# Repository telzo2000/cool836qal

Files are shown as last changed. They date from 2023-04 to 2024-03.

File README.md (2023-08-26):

# cool836qal

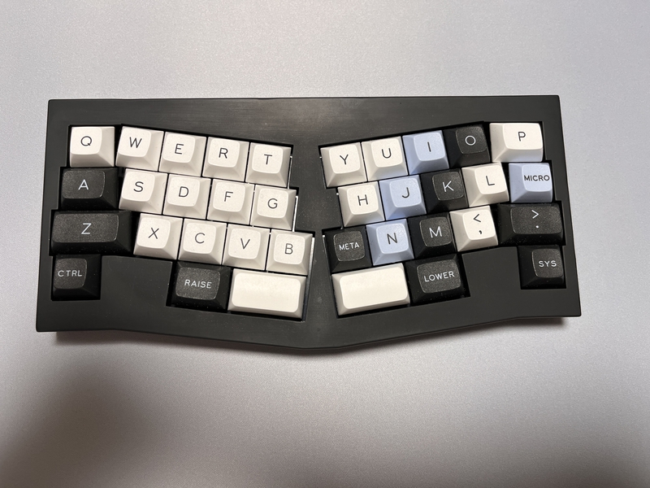
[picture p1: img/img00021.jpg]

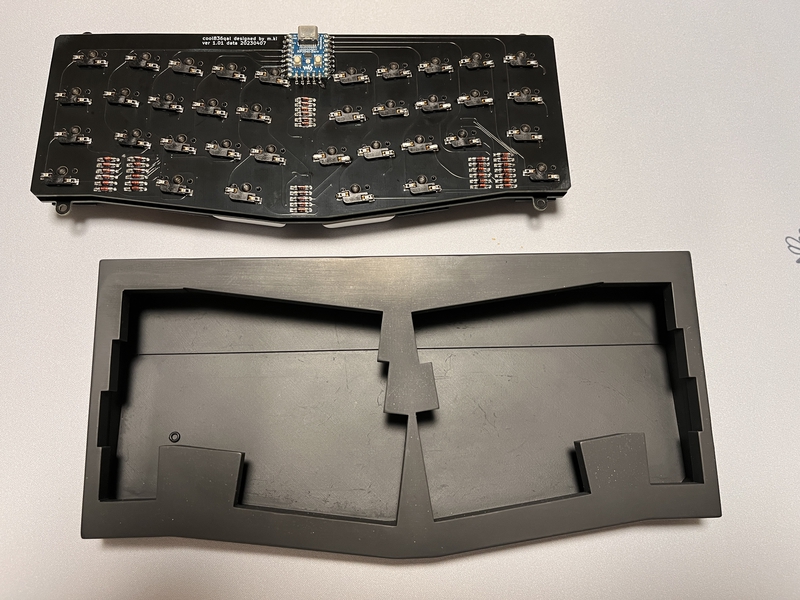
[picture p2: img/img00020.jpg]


A newly designed keyboard inspired by QAZ's Alice layout QAL and QALBLE.<br>
cool836qal uses RP2040-zero and runs on QMK_Firmware.
<br>
QAZのAliceレイアウトであるQALおよびQALBLEに影響を受けて、新しく設計したキーボードです。<br> cool836qalはRP2040-zeroを使い、QMK_Firmwareで動きます。
<br>

# Youtube
https://youtu.be/cL728gJIsGw?si=_ixN0UQqdAKH0zst

# Build log 

https://twitter.com/0002ozlet/status/1649874813920608256?s=20

# Build guide

https://github.com/telzo2000/cool836qal/blob/main/build_guide_cool836qal.md

# remap
https://remap-keys.app/catalog/FEmXx8GyuKYuJ5JSfcQG

# VIAL
https://github.com/telzo2000/cool836qal/tree/main/firmware

# Parts List

| No. | Patrs | Quantity | remarks | Suppliers | Cost |
|--|--|--|--|--|--|
|番号|名前|数|備考|調達先|参考価格（送料込）|<br>
|1|PCB|1|36key AlicLayout|[elecrow](https://www.elecrow.com)<br>[JLCPCB](https://jlcpcb.com)<br>[ALLPCB](https://www.allpcb.com)|５枚で20〜30ドル|<br>
|2|Switch Plate|1||[elecrow](https://www.elecrow.com)<br>[JLCPCB](https://jlcpcb.com)<br>[ALLPCB](https://www.allpcb.com)|５枚で20〜30ドル|<br>
|3|RP-2040Zero|1||[Talp Keyboard](https://talpkeyboard.net)|800円|
|4|Swith socket<br>スイッチソケット|36|cherry MX互換|[遊舎工房](https://yushakobo.jp)<br>[Talp Keyboard](https://talpkeyboard.net)<br>[Daily Craft Keyboard](https://shop.dailycraft.jp)等|10個で165円程度|
|5|Diode<br>ダイオード|36|リードタイプでもSMDでも可|[遊舎工房](https://yushakobo.jp)<br>[Talp Keyboard](https://talpkeyboard.net)<br>[Daily Craft Keyboard](https://shop.dailycraft.jp)等|100個で220円程度から|
|6|TopCase|1|3D Print|||
|7|BottomCase|1|3D Print||

In addition, you will need a USB cable, keycaps, etc.
<br>
この他に、USBケーブル、キーキャップ等が必要です。
<br>

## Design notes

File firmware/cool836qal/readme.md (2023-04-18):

# cool836qal

cool836qal

*A short description of the keyboard/project*

* Keyboard Maintainer: [m.ki](https://github.com/telzo2000)
* Hardware Supported: *The PCBs, controllers supported*
* Hardware Availability: *Links to where you can find this hardware*

Make example for this keyboard (after setting up your build environment):

    make cool836qal:default

Flashing example for this keyboard:

    make cool836qal:default:flash

See the [build environment setup](https://docs.qmk.fm/#/getting_started_build_tools) and the [make instructions](https://docs.qmk.fm/#/getting_started_make_guide) for more information. Brand new to QMK? Start with our [Complete Newbs Guide](https://docs.qmk.fm/#/newbs).

## Bootloader

Enter the bootloader in 3 ways:

* **Bootmagic reset**: Hold down the key at (0,0) in the matrix (usually the top left key or Escape) and plug in the keyboard
* **Physical reset button**: Briefly press the button on the back of the PCB - some may have pads you must short instead
* **Keycode in layout**: Press the key mapped to `QK_BOOT` if it is available

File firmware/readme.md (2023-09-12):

# Firmware

<br>

## VIA/REMAP

File name : cool836qal_via.uf2
<br>
<br>

## VIAL

File name : cool836qal_vial.uf2

20230912　The version of qmk_Firmware now corresponds to 0.22.

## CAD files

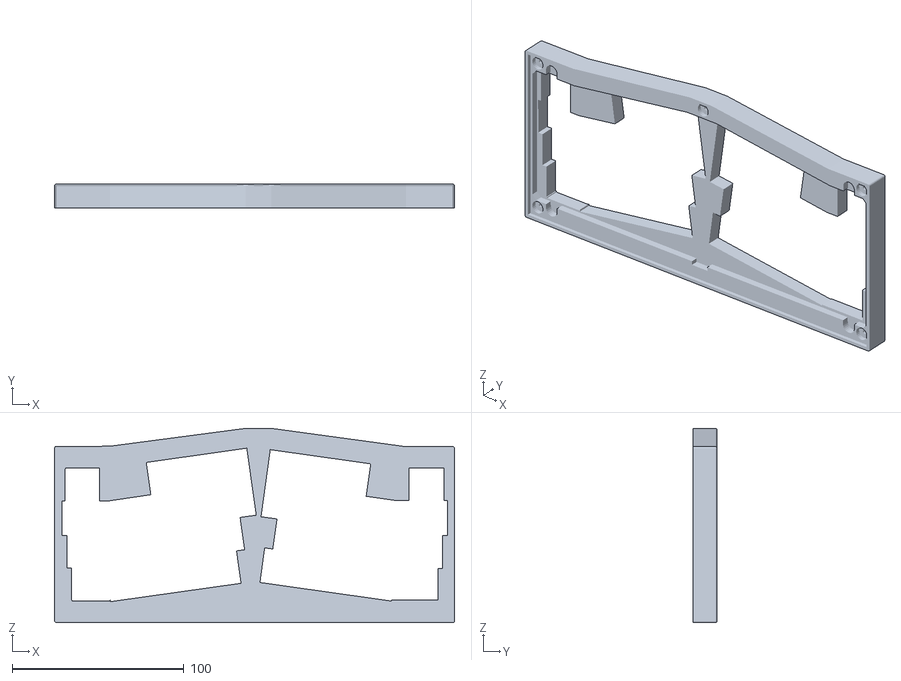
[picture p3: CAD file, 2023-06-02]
3D_case/cool836qal_casedesign_top_new.stl
233.0 x 14.0 x 113.2

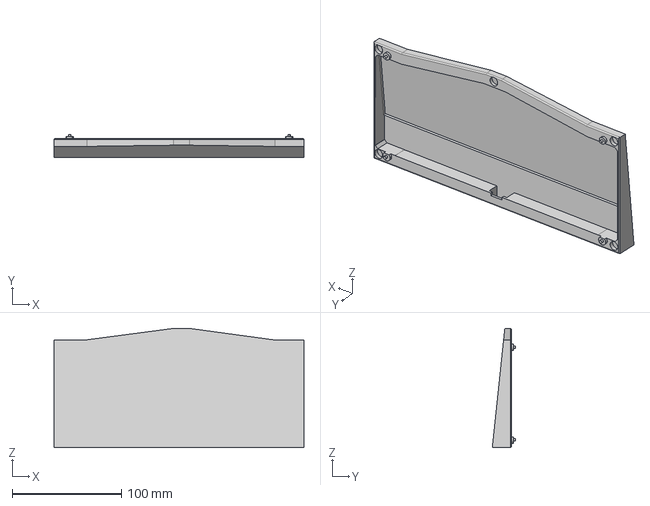
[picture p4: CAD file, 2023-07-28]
3D_case/step/cool836qal_casedesign_bottom v14.step
229.0 x 21.5 x 109.2 mm

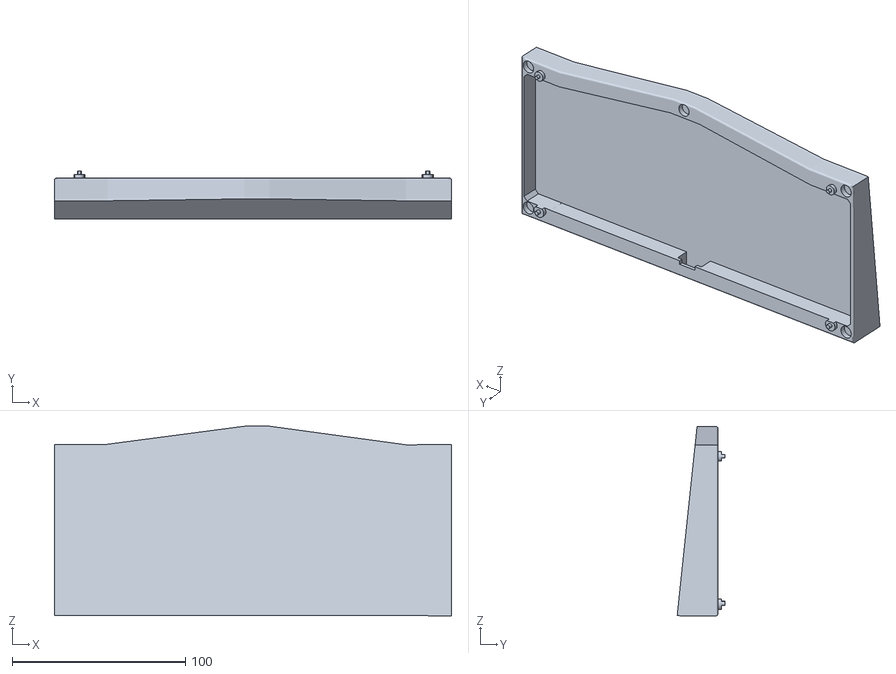
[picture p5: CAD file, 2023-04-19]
3D_case/cool836qal_casedesign_bottom.stl
229.0 x 27.5 x 109.3

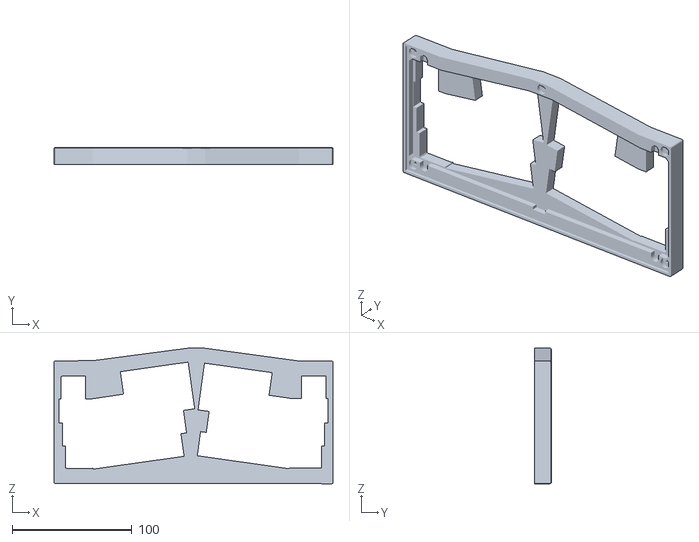
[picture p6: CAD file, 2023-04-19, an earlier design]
3D_case/cool836qal_casedesign_top_old.stl
233.0 x 14.0 x 113.2

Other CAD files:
3D_case/cool836qal_casedesign_low_bottom .stl
3D_case/step/cool836qal_casedesign_top v11.step
3D_case/step/cool836qal_casedesign_bottom v13.step

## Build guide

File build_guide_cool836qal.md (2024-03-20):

## Build guide

## Firmware

###  QMK_FIRMWARE

参考<br>

https://github.com/telzo2000/Hello_keyboard/blob/main/readme_about_firmware.md

[Here](https://github.com/telzo2000/cool836qal/tree/main/firmware)

<br>

[remap](https://remap-keys.app/catalog/FEmXx8GyuKYuJ5JSfcQG)

<br>

## Build 1

### 1 Diode soldering

Solder the diodes to the back of PCB.
<br>
PCBの裏面にダイオードのハンダ付けをします。
<br>
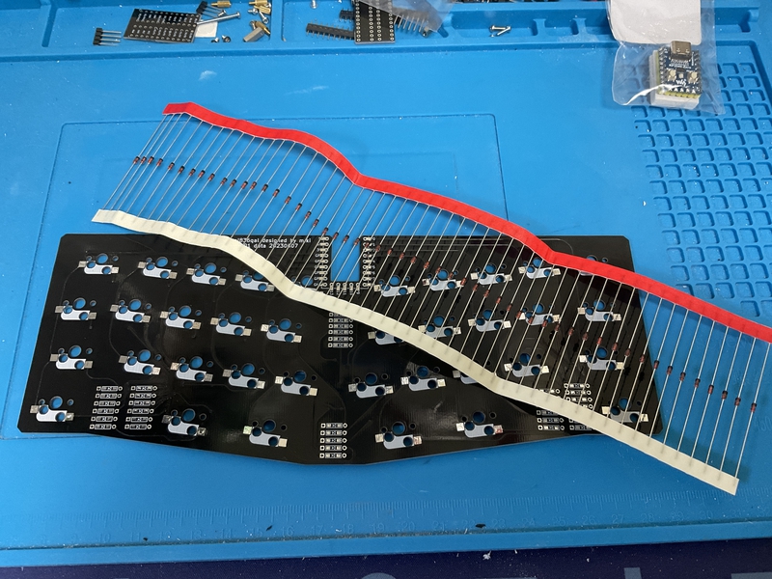
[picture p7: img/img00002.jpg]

There are lead type and SMD diodes.
<br>
ダイオードはリードタイプか、SMDがあります。
<br>
Here, we will explain the lead type soldering.
<br>
ここでは、リードタイプのハンダ付けの説明をします。
<br>

Use a lead bender to bend the legs of the diode.
<br>
リードベンダーを使い、ダイオードの足を曲げます。
<br>
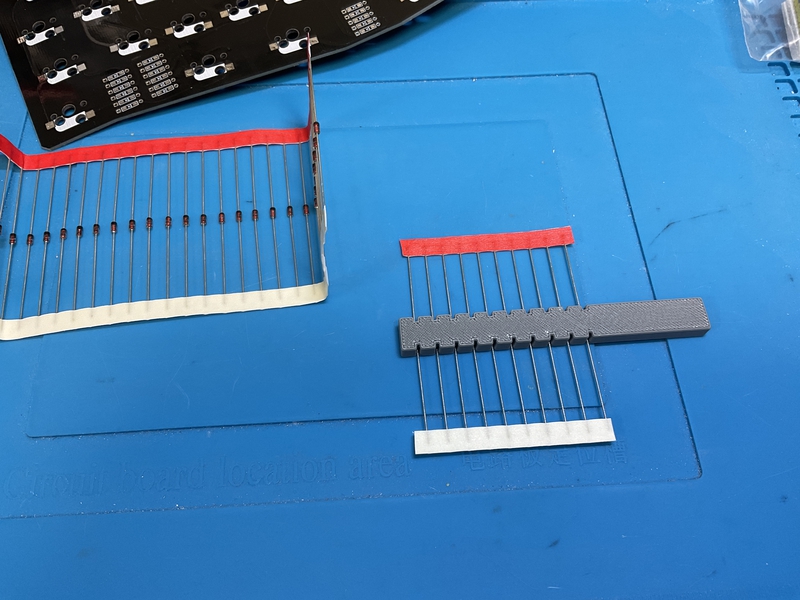
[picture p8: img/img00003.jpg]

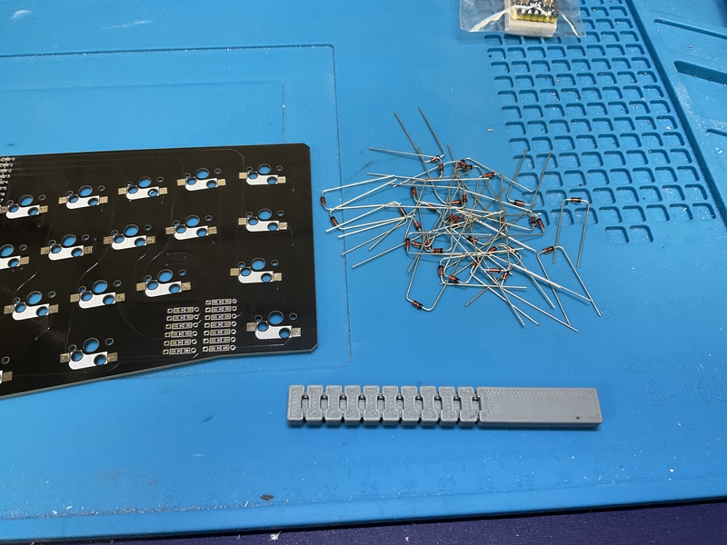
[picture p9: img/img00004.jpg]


Insert the diode into the board.
<br>
ダイオードを基板に挿しこみます。
<br>

Please pay attention to the orientation of the diode.
<br>
ダイオードの向きに注意してください。
<br>

Secure the diode with masking tape, then face up.
<br>
マスキングテープでダイオードを固定してから、表面を上にします。
<br>
Solder the protruding legs.
<br>
はみ出ている足部分に、ハンダ付けをします。
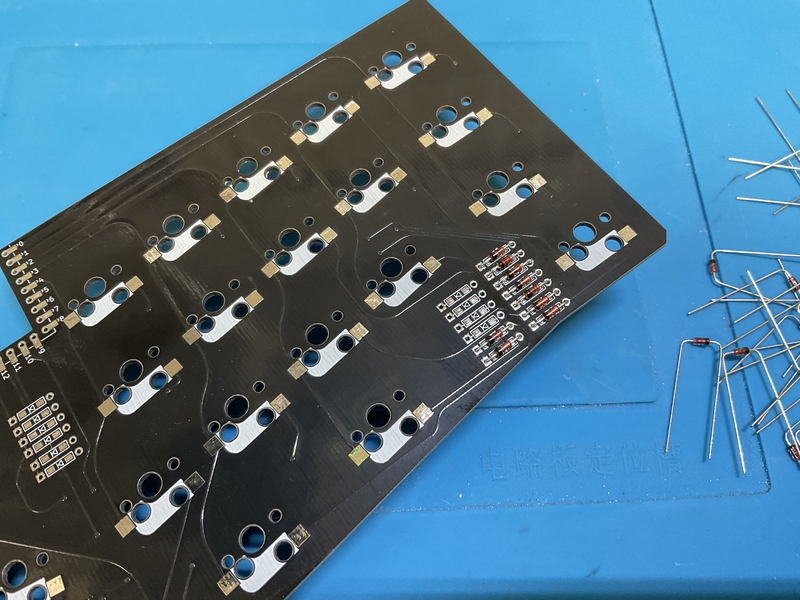
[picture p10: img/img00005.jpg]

<br>
After soldering, use nippers to cut off the protruding legs.
<br>
はんだ付けが終わったら、はみ出ている足をニッパーで切り取ってください。
<br>
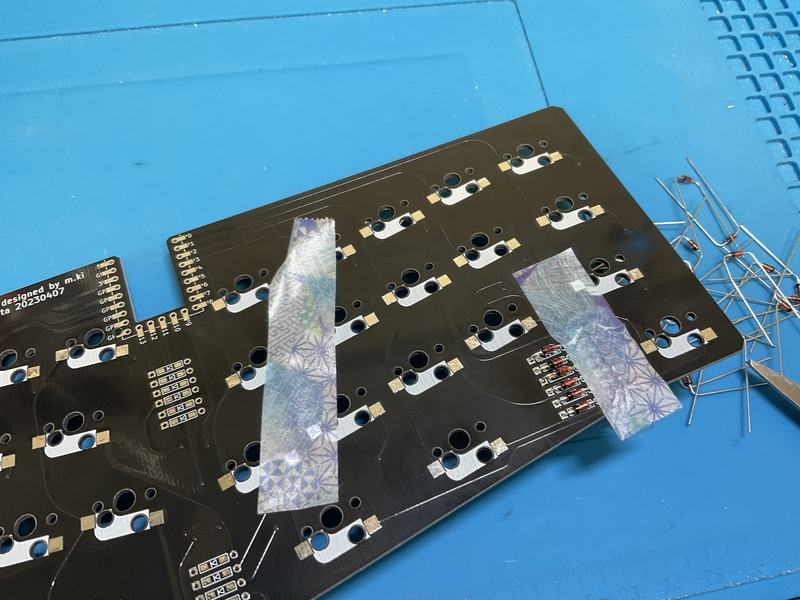
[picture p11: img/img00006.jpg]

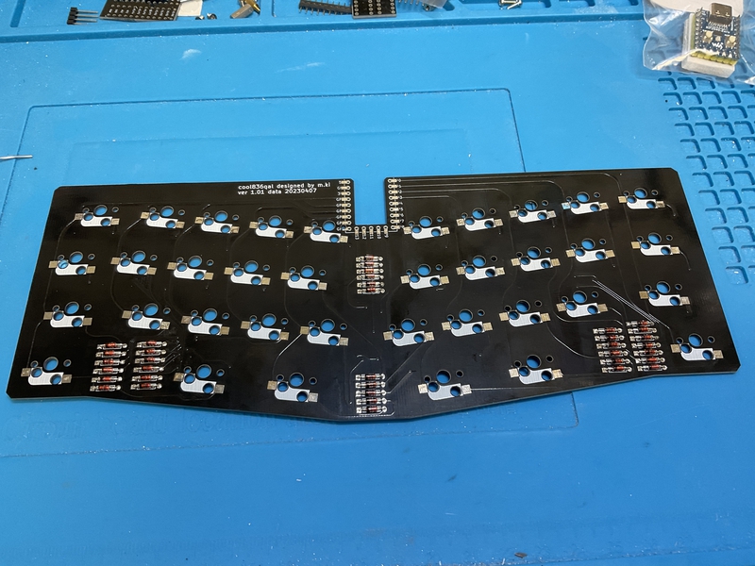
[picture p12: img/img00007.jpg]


[８倍速　Diodeハンダ付け動画](https://youtu.be/Yaodh2-XxV4)

<br>
<br>

### 2 Soldering switch sockets

Solder the switch sockets on the back side.
<br>
裏面にスイッチソケットのハンダ付けをします。
<br>
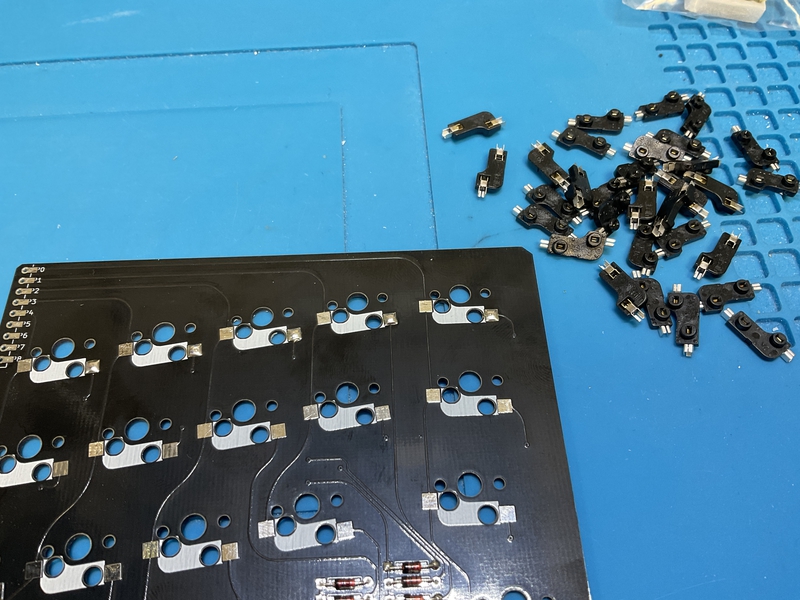
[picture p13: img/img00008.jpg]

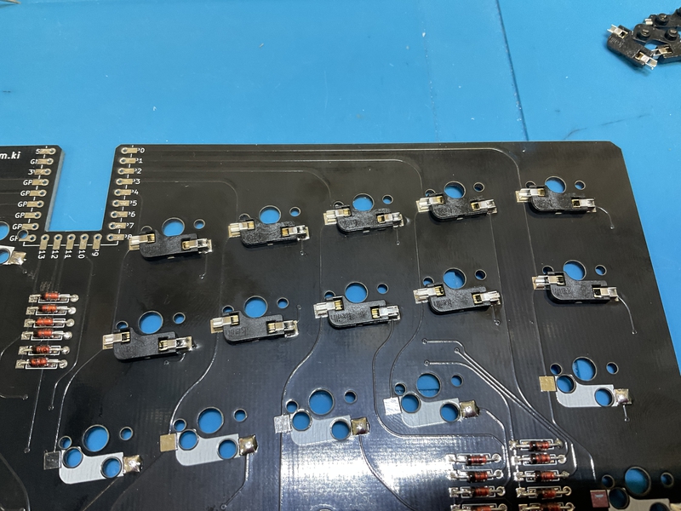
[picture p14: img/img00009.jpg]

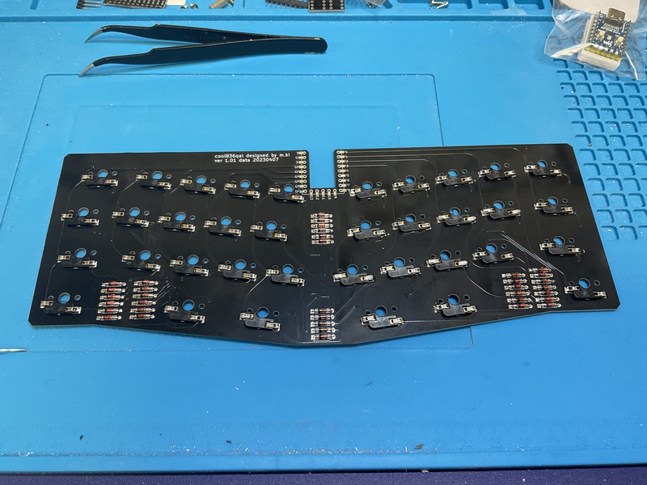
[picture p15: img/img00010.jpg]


[８倍速　Switch socketハンダ付け動画](https://youtu.be/E__mHvmIXQo)

<br><br>

### 3　Soldering RP-2040Zero  

The side on which the RP-2040Zero components are mounted is the front side, and the opposite side is the back side.
<br>
RP-2040Zeroの部品実装されている面を表面とし、反対側を裏面とします。
<br>
Place the back side of the PCB and the back side of the RP-2040Zero facing each other and solder the respective terminals.
<br>
PCBの裏面とRP-2040Zeroの裏面が向かい合うようにして置き、それぞれの端子をハンダ付けします。
<br>
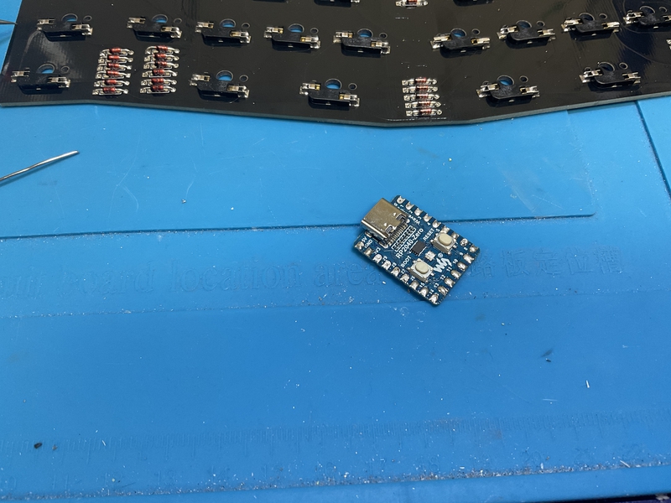
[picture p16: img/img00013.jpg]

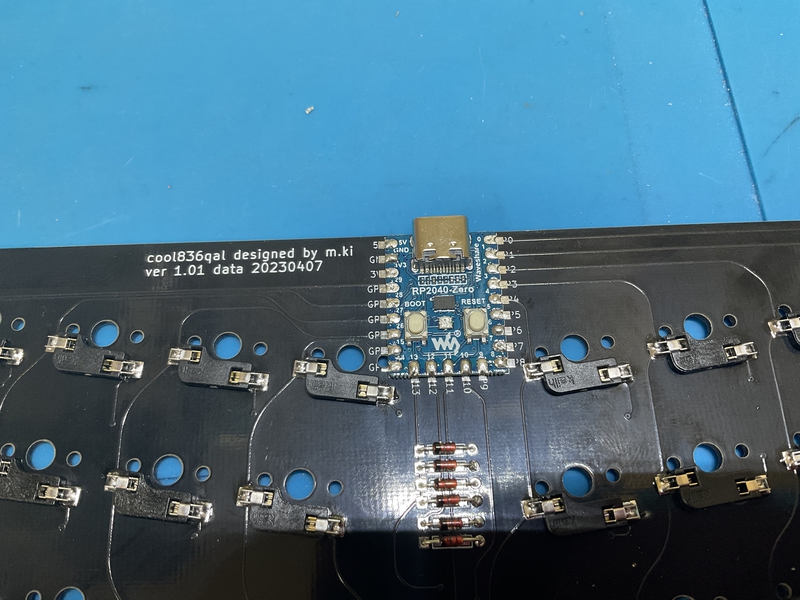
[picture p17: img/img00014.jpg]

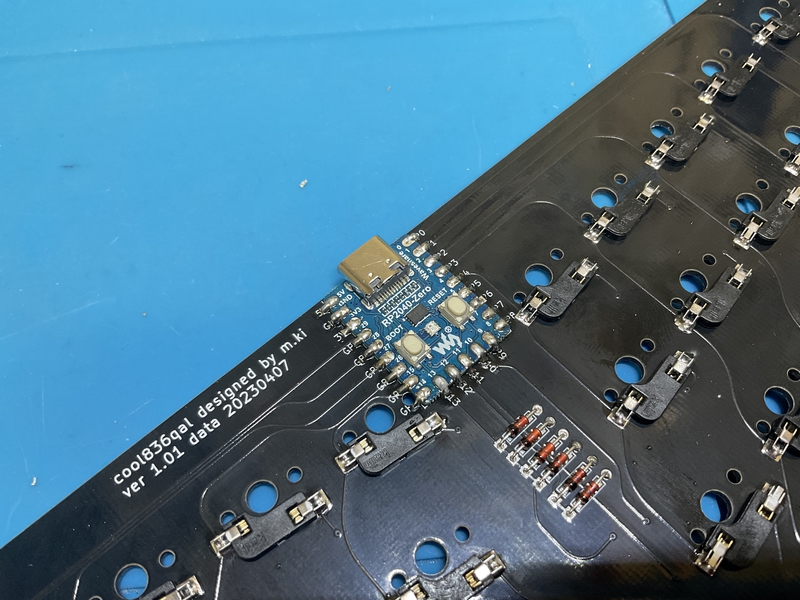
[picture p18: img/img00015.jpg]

<br>

### 4 Instorlling QMK＿Firmware

Install QMK_Firmware from your PC to RP-2040Zero.
<br>
QMK_FirmwareをPCからRP-2040Zeroにインストールしてください。
<br>
<br>
① Download https://github.com/telzo2000/cool836qal/blob/main/firmware/cool836qal_via.uf2 to your PC.
<br>
①https://github.com/telzo2000/cool836qal/blob/main/firmware/cool836qal_via.uf2 をPCにダウンロードしておく。

<br><br>
② Connect the PC and RP-2040Zero with a USB cable.
<br>
②PCとRP-2040ZeroをUSBケーブルで繋ぐ。
<br><br>
③Press the reset button while pressing the boost button on the RP-2040Zero.
<br>
③RP-2040Zeroのboostボタン押しながら、resetボタンを押す。
<br><br>
④Since there is a folder of RP-2040Zero on the PC screen, drag and drop the downloaded cool836qal.uf2 there.
<br>
④PC画面にはRP-2040Zeroのフォルダがあるので、そこに、ダウンロードしたcool836qal.uf2をドラッグアンドドロップする。
<br><br>

⑤Check if it is recognized by connecting to remap. Edit the keymap accordingly.
<br>
⑤remapに繋いで認識するかどうか確認する。合わせてキーマップの編集をする。

### Build 2(case)

### 1 Case

I will explain using a case printed by stereolithography of black resin ordered from JLCPCB. The procedure is basically the same for cases printed with Ankemake M5 for home use.
<br>
JLCPCBに発注したブラックレジンの光造形で印刷されたケースを使って説明します。家庭用AnkemakeM5で印刷したケースでも作業の手順は、基本的に同じです。
<br>
<br>
Fix the [magnets](https://www.amazon.co.jp/gp/product/B09BC46FQX/ref=ppx_yo_dt_b_asin_title_o00_s00?ie=UTF8&th=1) to the five dents inside the case with an adhesive or the like. There are 5 in the top case and 5 in the bottom case for a total of 10.Please pay attention to the polarity of the magnet. Make sure the top case and bottom case are magnetically attached.
<br>
ケースの内側にある５つの凹みに[磁石](https://www.amazon.co.jp/gp/product/B09BC46FQX/ref=ppx_yo_dt_b_asin_title_o00_s00?ie=UTF8&th=1)を接着剤などで固定します。トップケースに５箇所、ボトムケースに５箇所の合計10箇所です。
極性に注意してください。トップケースとボトムケースが磁力で着くようにしてください。
<br>
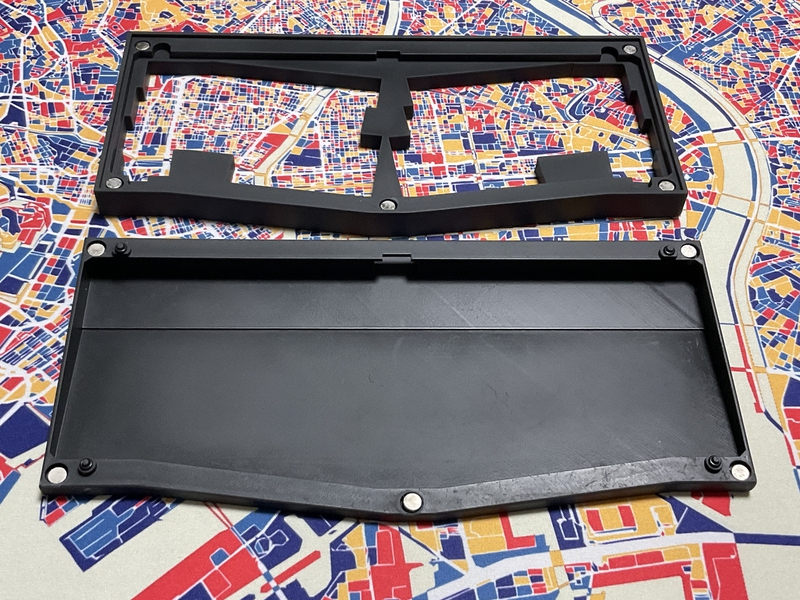
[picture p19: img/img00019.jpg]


As shown in the image below, attach rubber O-rings to the four protrusions on the bottom case. This makes it a gasket mount. You can do without the O-ring, but the PCB may move up and down inside the case.
<br>
下の画像のように、ボトムケースに4箇所の凸部にゴムのO-ringを装着します。これによりガスケットマウントとなります。O-ringはなくても大丈夫ですが、ケース内で、PCBが上下に動く可能性があります。
<br>
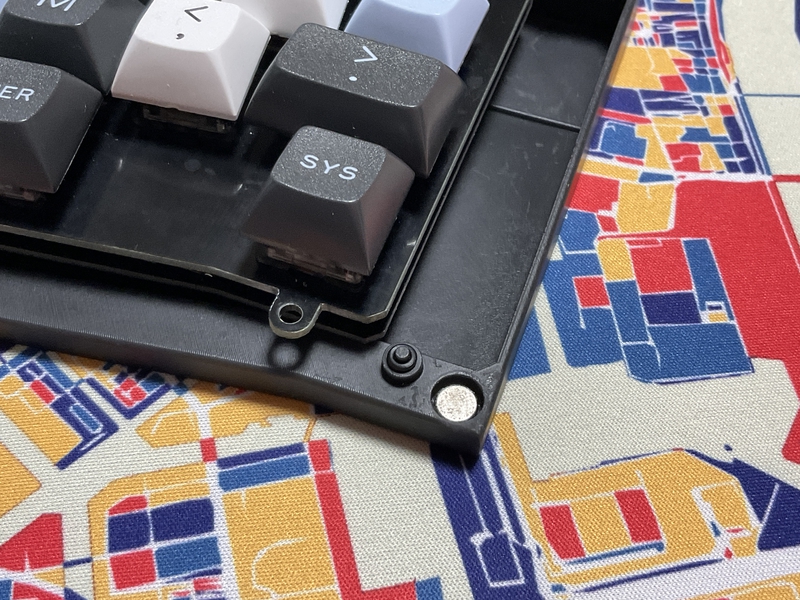
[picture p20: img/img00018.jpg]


The O-ring in the image is [this product](https://www.amazon.co.jp/gp/product/B07G4SM5SM/ref=ppx_yo_dt_b_asin_title_o03_s00?ie=UTF8&psc=1).
<br>
画像のO-ringは[この商品](https://www.amazon.co.jp/gp/product/B07G4SM5SM/ref=ppx_yo_dt_b_asin_title_o03_s00?ie=UTF8&psc=1)です。
<br>
<br>
Place the hole in the switch plate on the O-ring. And it is completed by covering the top case.
<br>
スイッチプレートの穴をO-ringに載せます。そして、トップケースを被せて完成です。
<br>
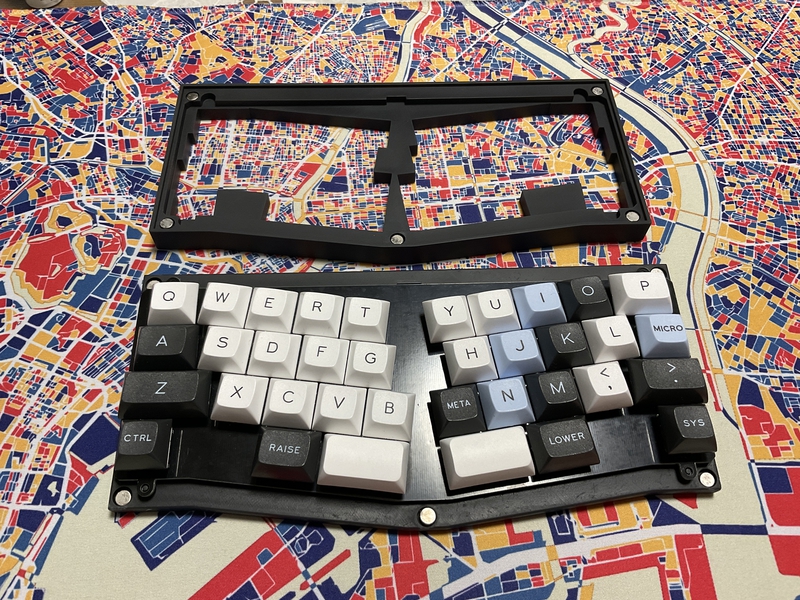
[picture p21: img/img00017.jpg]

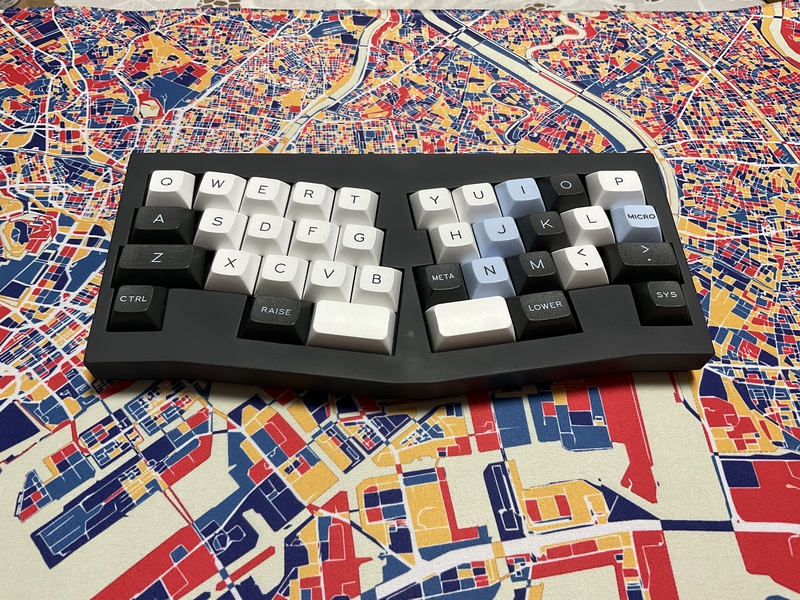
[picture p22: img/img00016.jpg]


Welcome to the world of 36 keys.
<br>
36キーの世界へようこそ。
<br>
